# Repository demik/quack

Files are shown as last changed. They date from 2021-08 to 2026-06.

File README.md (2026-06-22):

# Quack Mouse Converter   [][License]&nbsp;[][CI]

A dongle that allows various retro systems to use the `Apple Desktop Bus` as well as `Bluetooth 2+` mice through their `quadrature` mouse ports.

<br>
<br>
<br>

<div align = center>

[][Documentation]   
[][Firmware]   
[][PCB]   
[][Changelog]

<br>
<br>

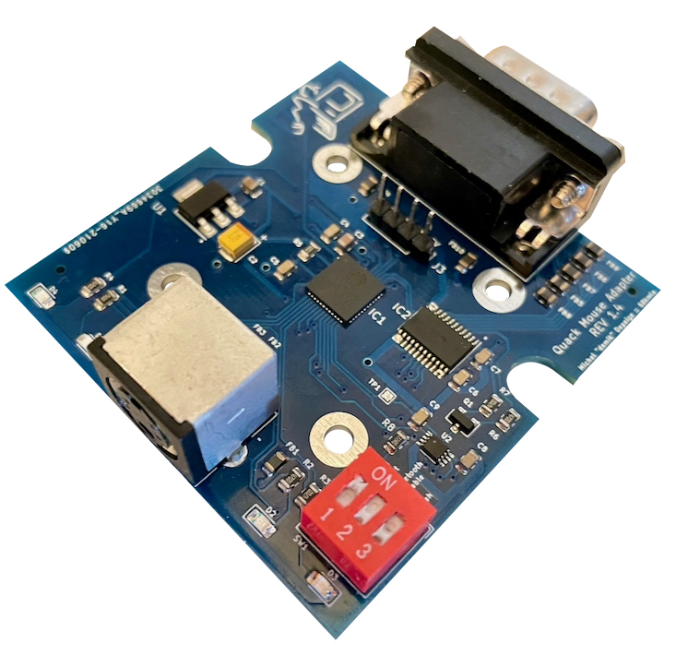
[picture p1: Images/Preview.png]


</div>

<br>
<br>

## Supported

#### Systems

<kbd>&nbsp;&nbsp;Macintosh 128 / 512 / Plus&nbsp;&nbsp;</kbd> 
<kbd>&nbsp;&nbsp;Apple Lisa&nbsp;&nbsp;</kbd> 
<kbd>&nbsp;&nbsp;Apple IIc&nbsp;&nbsp;</kbd> 
<a href="https://github.com/DosFox1/OSHintosh"><kbd>&nbsp;&nbsp;OSHintosh&nbsp;&nbsp;</kbd></a>

#### Connection Types

<kbd>  Apple Desktop Bus  </kbd> <kbd>  Bluetooth Classic 2+  </kbd>

<br>
<br>

<!----------------------------------------------------------------------------->

[Documentation]: https://github.com/demik/quack/wiki

[Changelog]: ChangeLog.md
[Firmware]: main/README.md
[License]: LICENSE
[PCB]: EDA/ChangeLog.md
[CI]: https://github.com/demik/quack/actions/workflows/idf.yml
[OSHintosh]: https://github.com/DosFox1/OSHintosh

<!-------------------------------[ Badges ]----------------------------------->

[Badge License]: https://img.shields.io/badge/License-Apache_2.0-961b1f?labelColor=D22128
[Badge CI]: https://github.com/demik/quack/actions/workflows/idf.yml/badge.svg?branch=master&event=push

<!-------------------------------[ Buttons ]----------------------------------->

[Button Documentation]: https://img.shields.io/badge/Documentation-0099E5?style=for-the-badge&logoColor=white&logo=BookStack
[Button Changelog]: https://img.shields.io/badge/Changelog-21375A?style=for-the-badge&logoColor=white&logo=AzureArtifacts
[Button Firmware]: https://img.shields.io/badge/Firmware-E5426E?style=for-the-badge&logoColor=white&logo=ROS
[Button PCB]: https://img.shields.io/badge/PCB-007c40?style=for-the-badge&logoColor=white&logo=PowerApps

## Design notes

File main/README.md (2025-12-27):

# Quack Firmware source code

### Supported SDK versions:

The code is designed to be build with ESP-IDF SDK version 5.5.2. To workaround some patchs or limitations of this specific release, you need to apply the patch located in the SDK subfolder

### Unsupported mouse conversions:

Functions are grouped into "domains" in different files. Each functions has a prefix for its own domain.
For example, adb_init() is the init function for the ADB Bus and is located in the adb.c source file.

List of relevant files:
- adb.* Apple Desktop Bus related functions
- blue.* Bluetooth related functions
- esp_hid_gap.* HID GAP library from Espressif
- gpio.* raw GPIO related functions
- led.* LED related functions
- m4848.h Header for Apple Hockey Puck mouse over Bluetooth emulation
- main.c Everything start here
- quad.c Quadrature related functions (mouse port)
- wii.* Wiimote driver

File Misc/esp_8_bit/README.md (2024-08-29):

# Quack X esp_8_bit
This is a crossover between two projects, that allow you to mod a Quack board to use with esp_8_bit firmware.
The result is a two players small box that can contains a few NES games and fit near your TV.

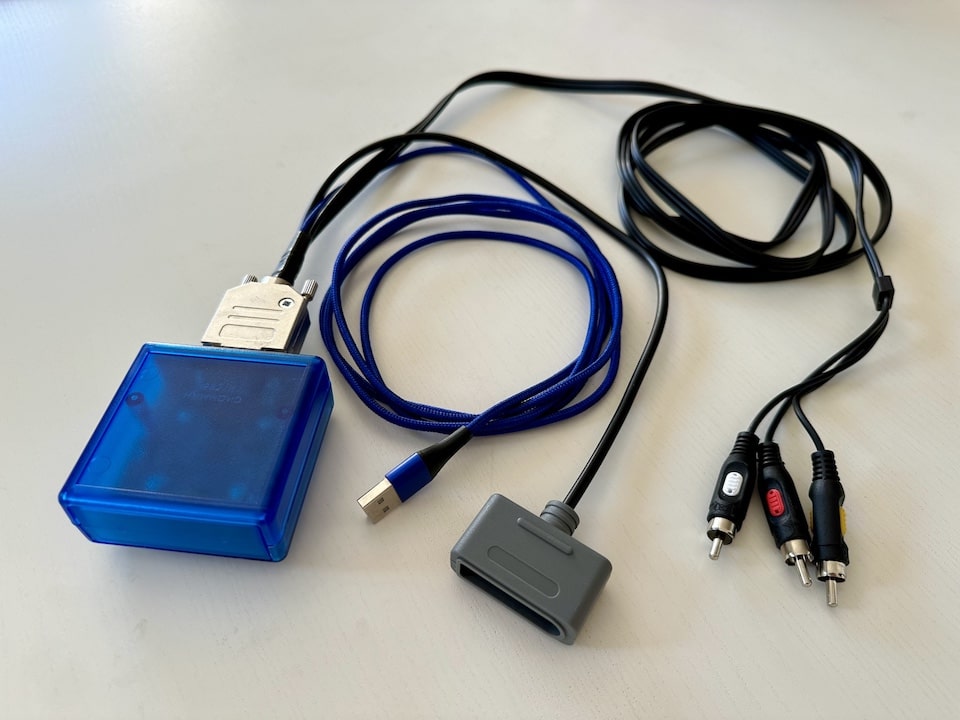
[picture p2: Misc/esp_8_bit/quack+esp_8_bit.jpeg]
quack+esp_8_bit


this is unsupported (outside of the quack project) and the parent project (esp_8_bit) is likely dead so this will likely not receive any updates or fixes

- parent project: [rossumur/esp_8_bit](https://github.com/rossumur/esp_8_bit)
- used patches from: [CornN64/esp_8_bit](https://github.com/CornN64/esp_8_bit)

it supports two players (one hardwired, either NES or SNES) and one Wiimote based. Unlike other builds, the hardwired connector runs at +5V (uses both level converters of the quack board), which allow the use of retro wireless adapters

schematic:

```
    -----------
    |         |
    |      25 |----------------------------------> video out
    |         |
    |         |   ------------
    |       2 |---| LVC 4245 |----/\/\/\/----|---> audio out
    |         |   ------------      1kΩ      |
    |         |                             ---
    |         |                             --- 10nF
    |  ESP32  |                              |
    |         |                              v gnd
    |         |
    |         |   ------------
    |       4 |---| LVC 2T45 |---< NES (or SNES) controller DATA
    |         |   ------------
    |         |   ------------
    |      12 |---| LVC 4245 |---> NES (or SNES) controller CLOCK
    |      14 |---| LVC 4245 |---> NES (or SNES) controller LATCH
    |         |   ------------
    |         |            5v <--> NES (or SNES) controller VCC
    |         |           gnd <--> NES (or SNES) controller GND
    |         |
    -----------

NES        ___
    DATA  |o o| NC
    LATCH |o o| NC
    CLOCK |o o/ 5V
    GND   |o_/

SNES       _
    5V    |o|
    CLOCK |o|
    LATCH |o|
    DATA  |o|
          |-|
    NC    |o|
    NC    |o|
    GND   |o|
           -

```

## Software

Since the esp_8_bit source code is old, you will need an old IDE (Arduino 1.8.14 with esp board 1.0.4)

there is a couple of patches in this directory that you will need to patch on top of [rossumur/esp_8_bit](https://github.com/rossumur/esp_8_bit)

- base.diff integrates patches from [CornN64/esp_8_bit](https://github.com/CornN64/esp_8_bit) and enable quack specific features (pinout, LEDs, DIP switches)
- controller.diff removes IR support, clean code and adds (S)NES controller support

```
> git clone https://github.com/rossumur/esp_8_bit.git
Cloning into 'esp_8_bit'...
remote: Enumerating objects: 345, done.
remote: Counting objects: 100% (15/15), done.
remote: Compressing objects: 100% (10/10), done.
remote: Total 345 (delta 5), reused 5 (delta 5), pack-reused 330 (from 1)
Receiving objects: 100% (345/345), 8.01 MiB | 8.04 MiB/s, done.
Resolving deltas: 100% (108/108), done.
> cd esp_8_bit
> patch -p1 < ../base.diff
patching file README.md
patching file esp_8_bit.ino
patching file 'src/emu.cpp'
patching file 'src/emu.h'
patching file 'src/emu_nofrendo.cpp'
patching file 'src/gui.cpp'
patching file 'src/hid_server/hid_server.cpp'
patching file 'src/video_out.h'
> patch -p1 < ../controller.diff
patching file 'src/ir_input.h'
patching file 'src/nintendo.h'
```

To avoid [this issue](https://github.com/rossumur/esp_8_bit/issues/19) you may want to change the partition layout as well. Check the solution into that issue, and also the boards.txt and quack_8_bit.csv files if needed

###

## Hardware

This mod is compatible with board revision 1.3 and 1.4

### PCB mods

hardware modifications needed

- remove Q1
- remove FB9
- remove D1
- bridge R1 or replace by 0Ω
- remove the Mini DIN-4 connector

Under the board:

- connect a wire from DE-9 pin 6 to D1 pin (+) on top of the board
- connect a wire from DE-9 pin 8 to Mini DIN-4 pin 1

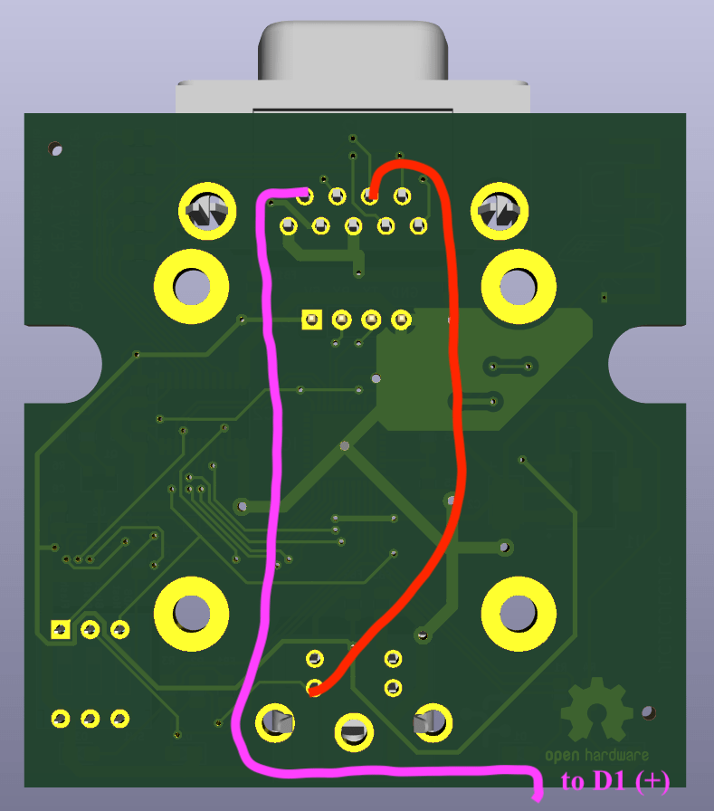
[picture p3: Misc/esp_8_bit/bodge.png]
bodge


### Adapter cable

You will need a NES or SNES extension cable, one triple RCA video cable, one USB cable (charge only is OK) and one DE-9 solderable connector
RC filtering circuit will be integrated into the connector. pinout is a follow (board side)

```
   _____________________
  /                     \
  \  1   2   3   4   5  /
   \   6   7   8   9   /
    \_________________/
```

| Pin | Connection | Notes |
|---|---|---|
| 1 | Ground | power ground & RCA shields here |
| 2 | +5V | USB +5V and (S)NES +5V connector go here |
| 3 | Ground | (S)NES ground + 10nF capacitor ground |
| 4 | NC | unused |
| 5 | Clock | (S)NES controller clock |
| 6 | Video | composite video out, yellow RCA |
| 7 | Sound | one pin of the 1kΩ resistor |
| 8 | Data | (S)NES controller data |
| 9 | Latch | (S)NES controller data |
| R | Resistor | solder capacitor on the other resistor pin & white + red RCA (+) wires |

isolate everything with hot glue or better

## Usage

Nothing different than the parent project as far as emulation goes

### Switches

Quack set of dip switches allows for the following settings

- ADB Host: (S)NES controller is player A, Wiimote player B or the other way around
- Bluetooth Disable: Kill BT Operation if not needed. More stable / less noise. Use with ADB Host to ON
- Flash: flash mode (GPIO0 to GND)

### LED

PCB LEDs are usable and do have basic functionality

- green: init done, board powered up
- yellow: valid (S)NES controller input received
- red: embedded flash operation in progress

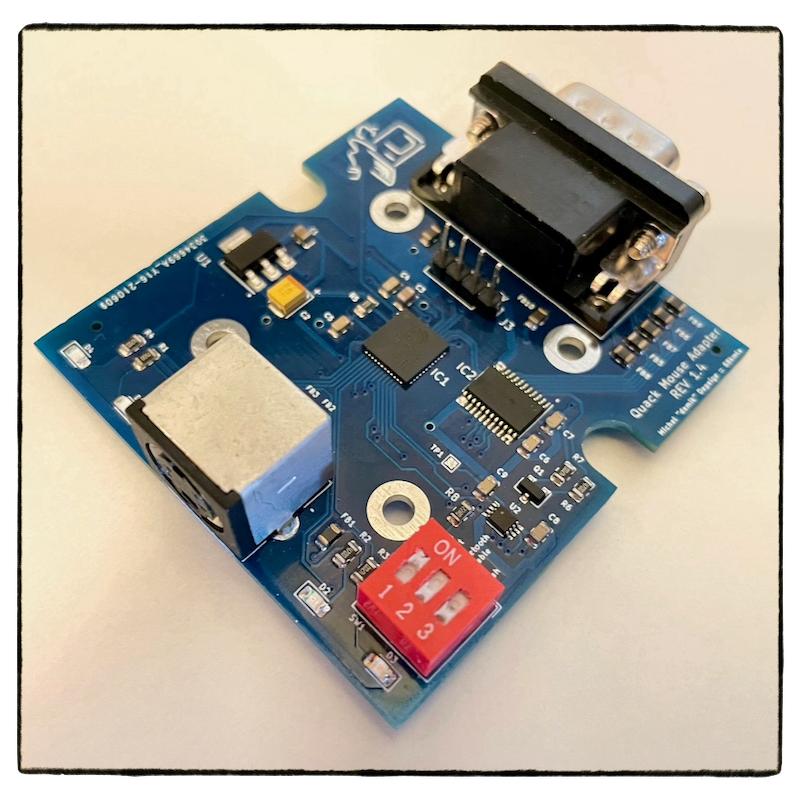
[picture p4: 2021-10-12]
Images/board.png

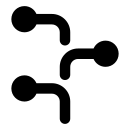
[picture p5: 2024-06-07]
EDA/Panels/Front/ADB.png

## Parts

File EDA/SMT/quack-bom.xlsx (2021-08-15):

quack-bom
Comment | Designator | Footprint | LCSC part number
ESP32-PICO-D4 | IC1 | QFN-48_EP_7.0x7.0x0.5P | C193707
74LVC4245APWR | IC2 | TSSOP-24_4.4x7.8x0.65P | C7859
10uF 25V | C1 C3 | 0805 | C15850
Tantalum 100uF 6.3V | C2 | 3528 | C16133
AMS1117-3.3 | U1 | SOT-223 | C6186
74LVC2T45DCURG4 | U2 | VSSOP-8_2.0x2.3x0.5P | C139382
Blue LED | D1 | 0805 | C2293
Yellow LED | D2 | 0805 | C2296
Red LED | D3 | 0805 | C84256
Green LED | D4 | 0805 | C2297
MOFSET P–Channel | Q1 | SOT-23-3 | C8492
22Ω ±1% 1/8W | R8 | 0805 | C17561
470Ω ±1% 1/8W | R1 R2 R3 R6 R7 | 0805 | C17710
1.2kΩ ±1% 1/8W | R4 | 0805 | C17379
100NF 50V | C4 C5 C6 C7 C8 C9 | 0805 | C49678
10KΩ ±1% 1/8W | R5 | 0805 | C17414
Bead 0805 | FB1 FB2 FB3 FB4 FB5 FB6 FB7 FB8 FB9 FB10 | 0805 | C1017

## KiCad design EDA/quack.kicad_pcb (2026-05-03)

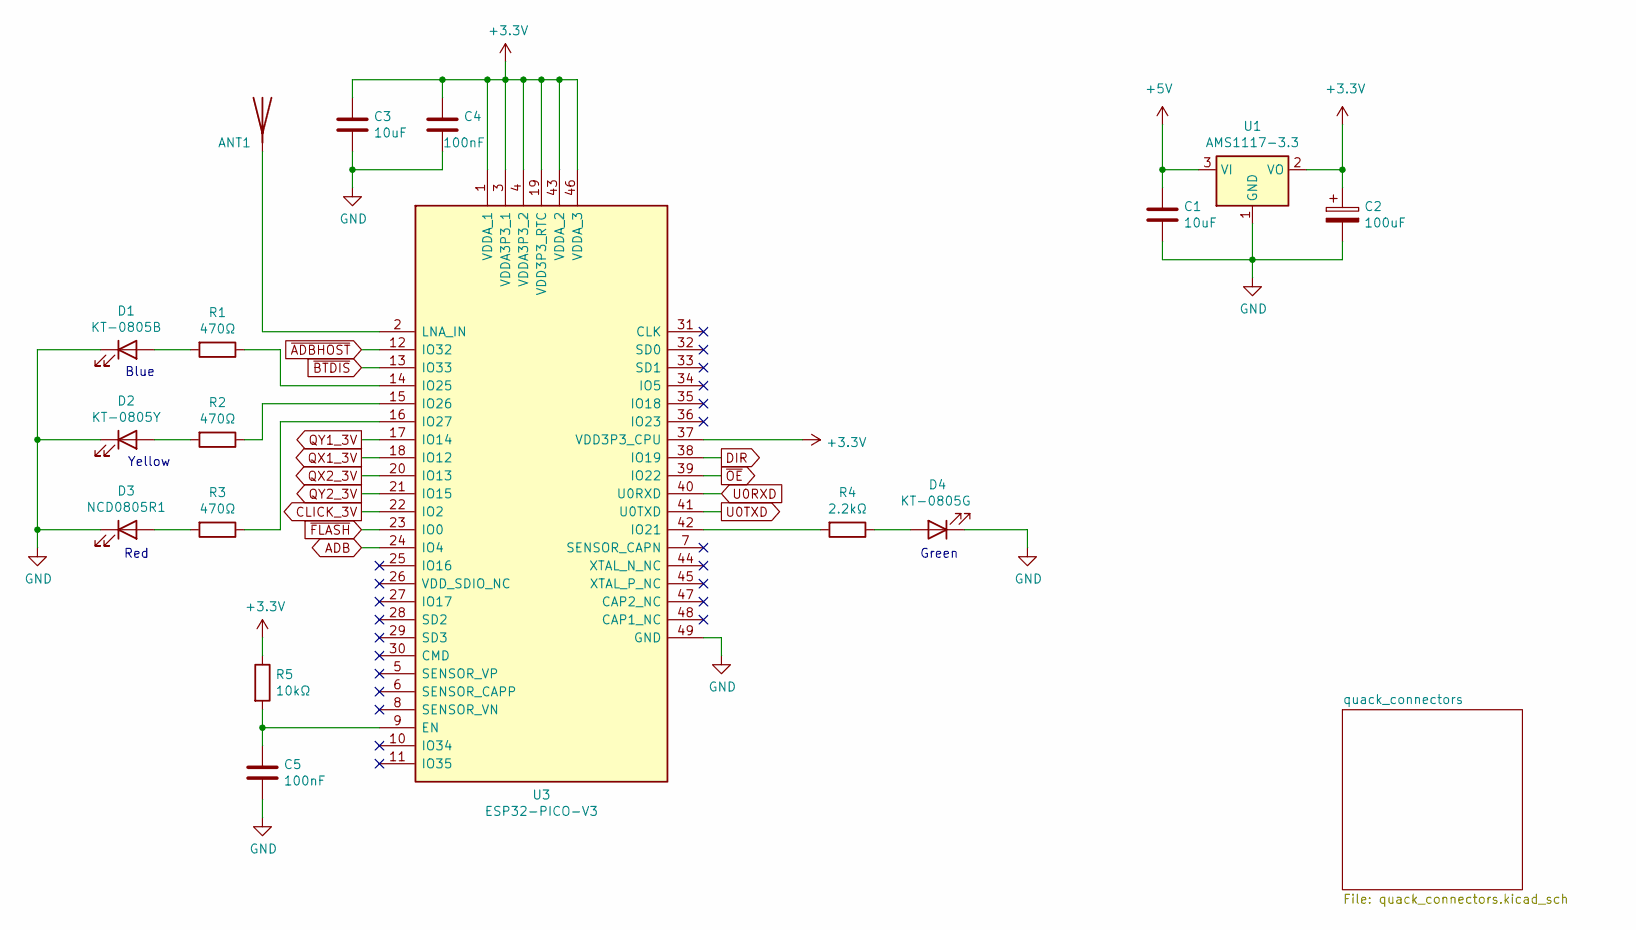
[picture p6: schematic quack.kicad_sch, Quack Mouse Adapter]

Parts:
ANT1: Antenna_Shield; Texas_SWRA117D_2.4GHz_Right
C1, C3: 10uF; C_0805_2012Metric
C2: 100uF; CP_EIA-3528-12_Kemet-T
C4, C5: 100nF; C_0805_2012Metric
D1: KT-0805B; LED_0805_2012Metric
D2: KT-0805Y; LED_0805_2012Metric
D3: NCD0805R1; LED_0805_2012Metric
D4: KT-0805G; LED_0805_2012Metric
R1, R2, R3: 470Ω; R_0805_2012Metric
R4: 2.2kΩ; R_0805_2012Metric
R5: 10kΩ; R_0805_2012Metric
U1: AMS1117-3.3; SOT-223-3_TabPin2
U3: ESP32-PICO-V3; QFN-48-1EP_7x7mm_P0.5mm_EP5.3x5.3mm; Mouser Part Number 356-ESP32-PICO-V3

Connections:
+3.3V: C2.1, C3.1, C4.1, R5.1, U1.2 (VO), U3.1 (VDDA_1), U3.3 (VDDA3P3_1), U3.4 (VDDA3P3_2), U3.19 (VDD3P3_RTC), U3.37 (VDD3P3_CPU), U3.43 (VDDA_2), U3.46 (VDDA_3); also elsewhere on the board
+5V: C1.1, U1.3 (VI); also elsewhere on the board
ADB: U3.24 (IO4); also elsewhere on the board
CLICK_3V: U3.22 (IO2); also elsewhere on the board
DIR: U3.38 (IO19); also elsewhere on the board
GND: C1.2, C2.2, C3.2, C4.2, C5.2, D1.1 (K), D2.1 (K), D3.1 (K), D4.1 (K), U1.1 (GND), U3.49 (GND); also elsewhere on the board
unnamed: ANT1.1 (A), U3.2 (LNA_IN)
unnamed: D1.2 (A), R1.2
unnamed: D2.2 (A), R2.2
unnamed: D3.2 (A), R3.2
unnamed: D4.2 (A), R4.1
unnamed: C5.1, R5.2, U3.9 (EN)
unnamed: R4.2, U3.42 (IO21)
unnamed: R1.1, U3.14 (IO25)
unnamed: R2.1, U3.15 (IO26)
unnamed: R3.1, U3.16 (IO27)
QX1_3V: U3.18 (IO12); also elsewhere on the board
QX2_3V: U3.20 (IO13); also elsewhere on the board
QY1_3V: U3.17 (IO14); also elsewhere on the board
QY2_3V: U3.21 (IO15); also elsewhere on the board
U0RXD: U3.40 (U0RXD); also elsewhere on the board
U0TXD: U3.41 (U0TXD); also elsewhere on the board
~ADBHOST: U3.12 (IO32); also elsewhere on the board
~BTDIS: U3.13 (IO33); also elsewhere on the board
~FLASH: U3.23 (IO0); also elsewhere on the board
~OE: U3.39 (IO22); also elsewhere on the board

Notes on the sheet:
Blue
Red
Green
Yellow

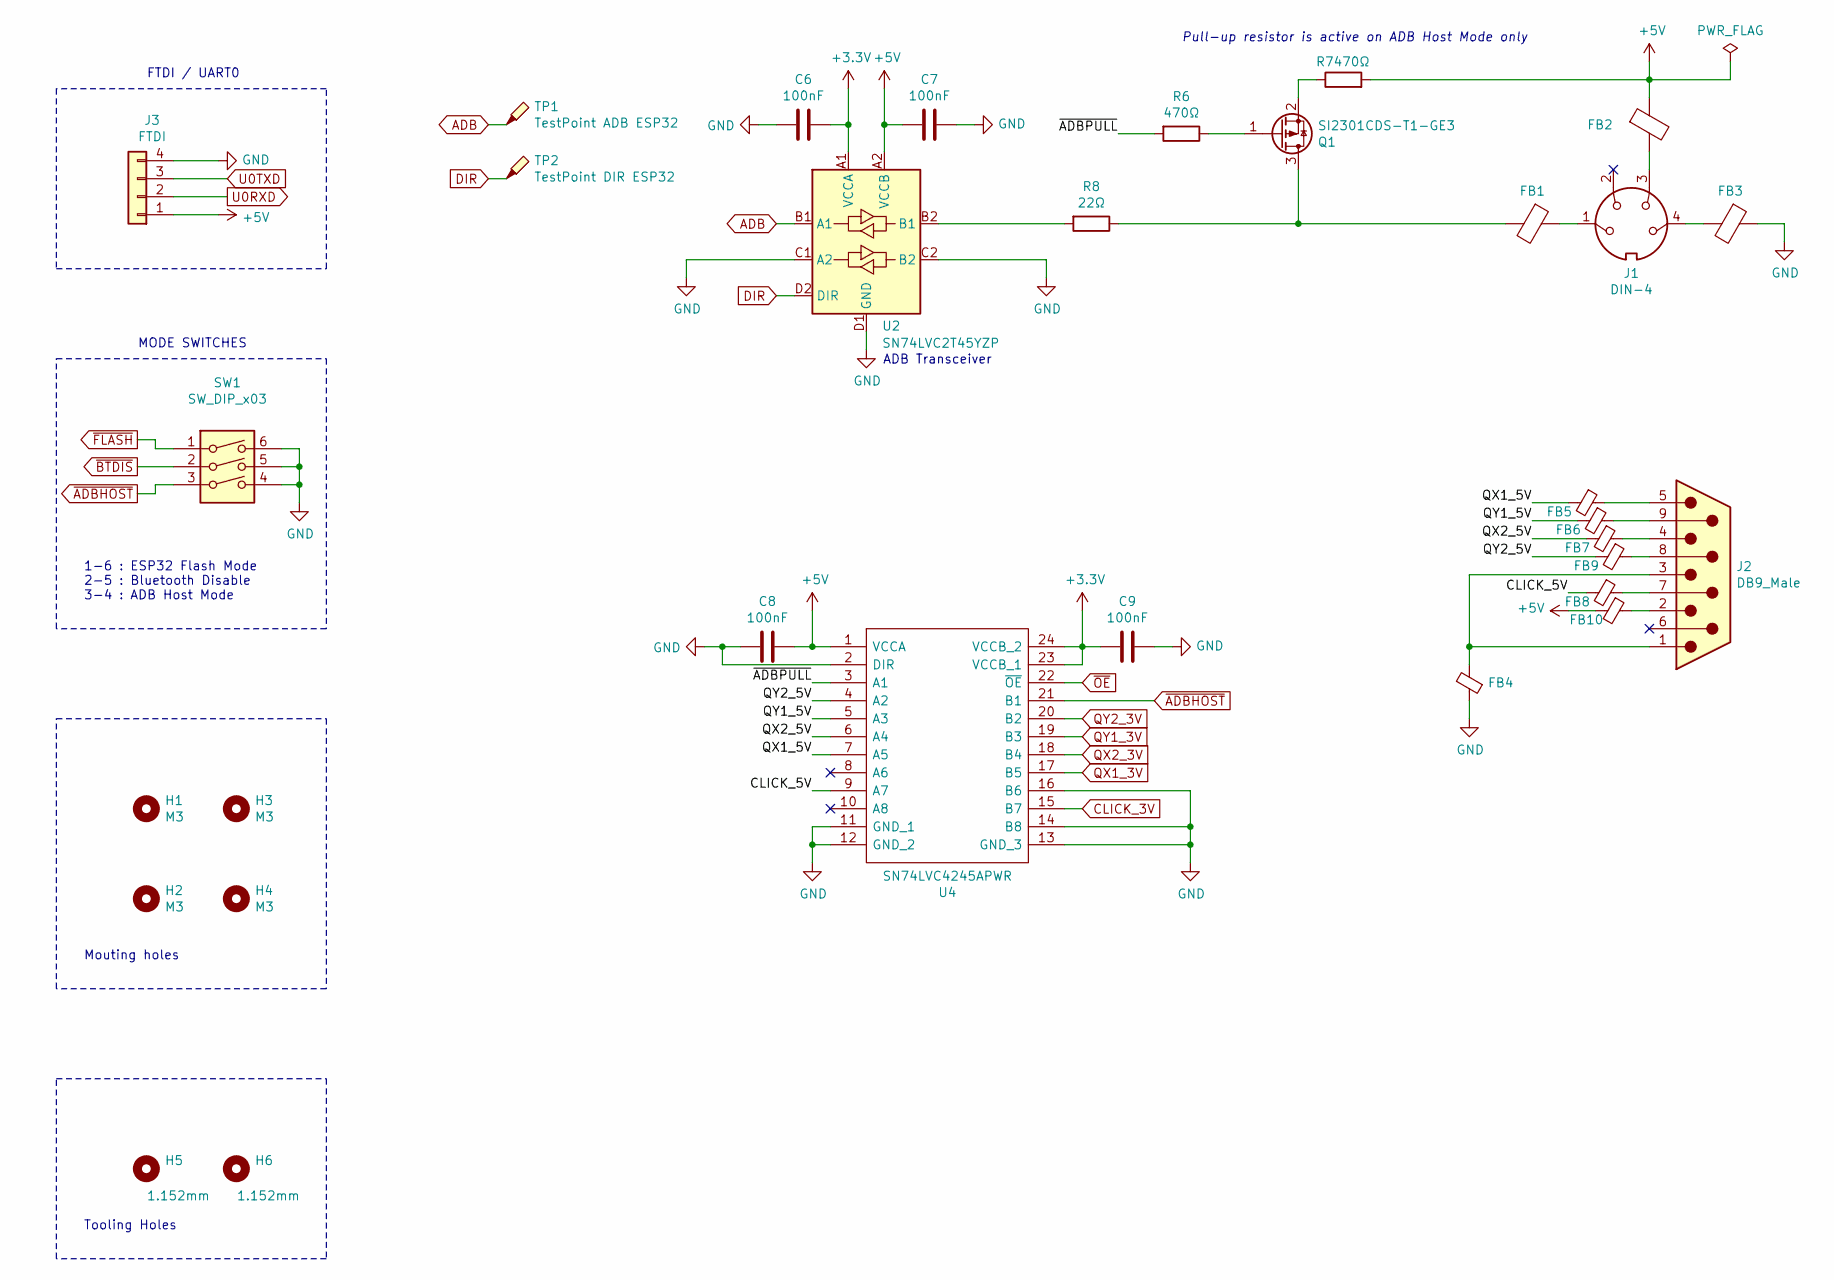
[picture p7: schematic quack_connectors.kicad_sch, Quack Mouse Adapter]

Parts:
C6, C7, C8, C9: 100nF; C_0805_2012Metric
FB1, FB2, FB3, FB4, FB5, FB6, FB7, FB8, FB9, FB10: GZ2012D601TF; L_0805_2012Metric
H1, H2, H3, H4: M3; MountingHole_3.2mm_M3_Pad
H5, H6: 1.152mm; MountingHole_1.152mm
J1: DIN-4; 5749181-1
J2: DB9_Male; 23018431
J3: FTDI; PinHeader_1x04_P2.54mm_Vertical
Q1: SI2301CDS-T1-GE3; SOT-23
R6, R7: 470Ω; R_0805_2012Metric
R8: 22Ω; R_0805_2012Metric
SW1: SW_DIP_x03; SW_DIP_SPSTx03_Slide_9.78x9.8mm_W7.62mm_P2.54mm
TP1: TestPoint ADB ESP32; TestPoint_Pad_1.0x1.0mm
TP2: TestPoint DIR ESP32; TestPoint_Pad_1.0x1.0mm
U2: SN74LVC2T45YZP; Texas_DSBGA-8_0.9x1.9mm_Layout2x4_P0.5mm
U4: SN74LVC4245APWR; TSSOP-24_4.4x7.8mm_P0.65mm; Mouser Part Number 595-SN74LVC4245APWR

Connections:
+3.3V: C6.1, C9.2, U2.A1 (VCCA), U4.23 (VCCB_1), U4.24 (VCCB_2); also elsewhere on the board
+5V: C7.2, C8.1, FB2.1, FB10.2, J3.1, R7.2, U2.A2 (VCCB), U4.1 (VCCA); also elsewhere on the board
/quack_connectors/CLICK_5V: FB8.2, U4.9 (A7)
/quack_connectors/QX1_5V: FB5.2, U4.7 (A5)
/quack_connectors/QX2_5V: FB7.2, U4.6 (A4)
/quack_connectors/QY1_5V: FB6.2, U4.5 (A3)
/quack_connectors/QY2_5V: FB9.2, U4.4 (A2)
/quack_connectors/~ADBPULL: R6.2, U4.3 (A1)
ADB: TP1.1, U2.B1 (A1); also elsewhere on the board
CLICK_3V: U4.15 (B7); also elsewhere on the board
DIR: TP2.1, U2.D2 (DIR); also elsewhere on the board
GND: C6.2, C7.1, C8.2, C9.1, FB3.1, FB4.1, J3.4, SW1.4, SW1.5, SW1.6, U2.C1 (A2), U2.C2 (B2), U2.D1 (GND), U4.2 (DIR), U4.11 (GND_1), U4.12 (GND_2), U4.13 (GND_3), U4.14 (B8), U4.16 (B6); also elsewhere on the board
unnamed: FB1.1, J1.1
unnamed: FB2.2, J1.3
unnamed: FB3.2, J1.4
unnamed: FB4.2, J2.1, J2.3
unnamed: FB5.1, J2.5
unnamed: FB6.1, J2.9
unnamed: FB7.1, J2.4
unnamed: FB8.1, J2.7
unnamed: FB9.1, J2.8
unnamed: FB10.1, J2.2
unnamed: FB1.2, Q1.3 (D), R8.1
unnamed: Q1.1 (G), R6.1
unnamed: Q1.2 (S), R7.1
unnamed: R8.2, U2.B2 (B1)
QX1_3V: U4.17 (B5); also elsewhere on the board
QX2_3V: U4.18 (B4); also elsewhere on the board
QY1_3V: U4.19 (B3); also elsewhere on the board
QY2_3V: U4.20 (B2); also elsewhere on the board
U0RXD: J3.2; also elsewhere on the board
U0TXD: J3.3; also elsewhere on the board
~ADBHOST: SW1.3, U4.21 (B1); also elsewhere on the board
~BTDIS: SW1.2; also elsewhere on the board
~FLASH: SW1.1; also elsewhere on the board
~OE: U4.22 (~OE); also elsewhere on the board

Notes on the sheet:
1-6 : ESP32 Flash Mode 2-5 : Bluetooth Disable 3-4 : ADB Host Mode
Mouting holes
MODE SWITCHES
ADB Transceiver
Pull-up resistor is active on ADB Host Mode only
Tooling Holes
FTDI / UART0

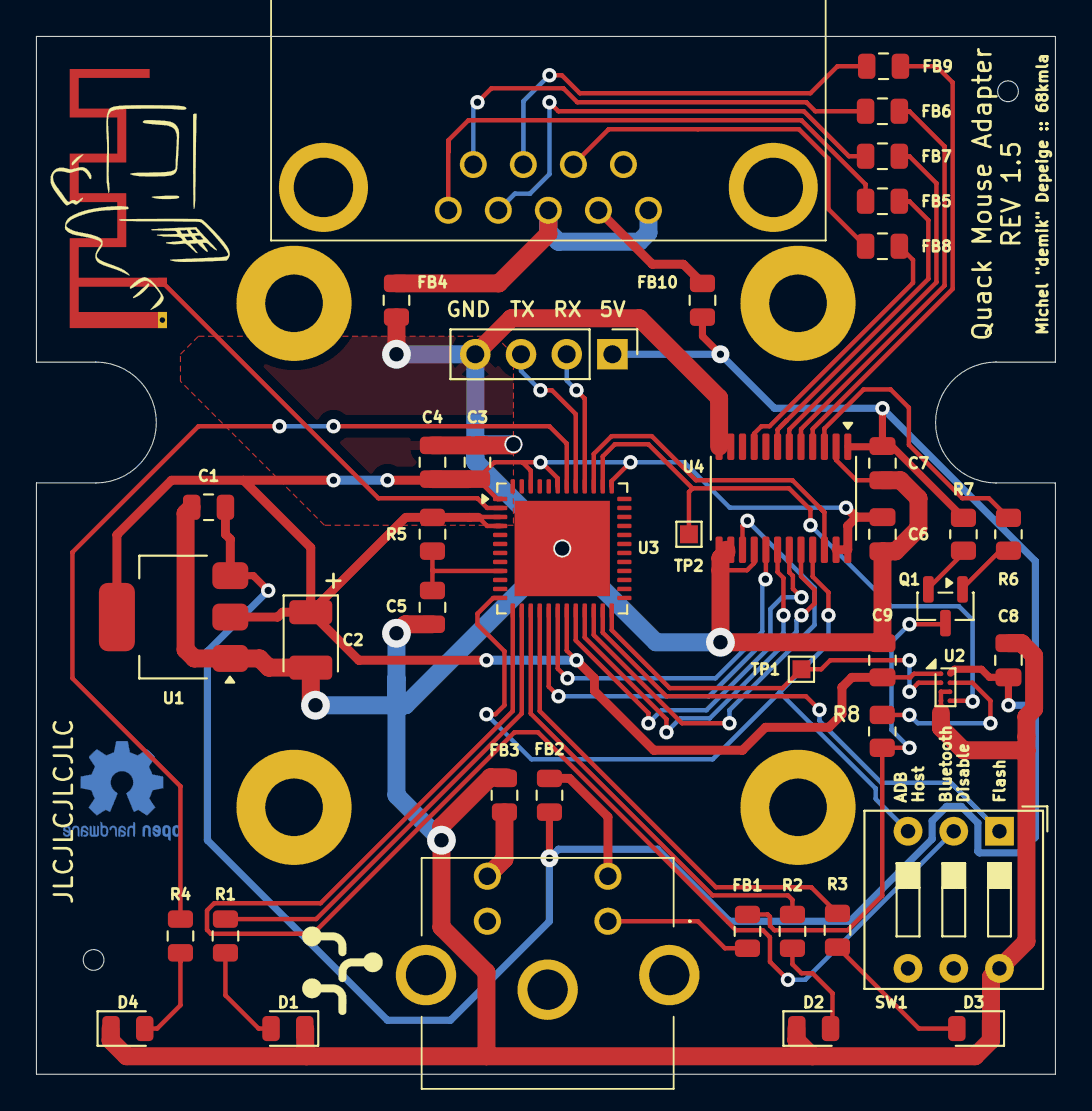
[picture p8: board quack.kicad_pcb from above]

Board: 2 copper layers, 56.6 x 57.7 mm, 49 parts (0 on the bottom side), 46 nets.

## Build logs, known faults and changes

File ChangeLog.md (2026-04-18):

## v1.5.0
- update to ESP-IDF v5.5.4
	- https://github.com/espressif/esp-idf/releases/tag/v5.5.4
	- this fixes a few buffers overflows and other rare stuff in Bluedroid
- 1.5.x series is compatible with 1.3 to 1.5 PCBs (EDA subfolder)
- new bespoke ADB RX driver has been developed based on the legacy RMT driver
	- the functionality is the same as the v1.4 one but it's more SDK future proof

## v1.4.11
- update to ESP-IDF v5.4.2
	- https://github.com/espressif/esp-idf/releases/tag/v5.4.2
	- under the hood fixes of some rare stabilities issues

## v1.4.10
- update to ESP-IDF v5.4.0
	- https://github.com/espressif/esp-idf/releases/tag/v5.4
	- fixed stabilities where Quack would reboot on BT disconnect
- added support for Apple Mighty Mouse (Bluetooth)

## v1.4.9
- added basic support for some PDP Rock Candy Wiimotes
	- BDAs starting from the range 08:03:64
	- remote doesn't reconnect correctly, have to repair each time

## v1.4.8
- added support for MacAlly Joystick
- added support for Nintendo Wiimotes
	- D-pad movement working, click on B, half-click on A
	- selectable movement speed on the Weemote + LED feedback
	- this lay the framework to add drivers for some unsupported devices

## v1.4.7
- new feature: half click on right BT click (similar to some ADB devices)
- workarounds for v1.4.6 green led regression

## v1.4.6
- added support for ADB composite devices (Kensignton and some Joysticks)
- fixed ADB start and stop bit times (65 µs vs 70 µs, error in AN591)
- update to ESP-IDF v5.2.2
	- https://github.com/espressif/esp-idf/releases/tag/v5.2.2
	- fixed flash corruption after pairing too much devices (20+)
	- fixed ADB host mode where the ESP boot was too fast (v5.2 regression)

## v1.4.5
- update to ESP-IDF v5.1.2
	- https://github.com/espressif/esp-idf/releases/tag/v5.1.2
	- big background update, lot of cleaning and rewrites
	- as most patches are now mainstream, sdk patching is now minimal
	- removed direct ABI bluedroid call

## v1.4.4
- update to ESP-IDF v4.2.3:
	- https://github.com/espressif/esp-idf/releases/tag/v4.2.3
	- mostly bluetooth related security and bug fixes

## v1.4.3
- provides some slight acceleration and desceleration on bluetooth mouses

## v1.4.2
- added support for MicroSpeed MacTRAC 2.0
- fixed a BT led state when a device reconnect while scanning

## v1.4.1
- update to ESP-IDF v4.2.2:
	- https://github.com/espressif/esp-idf/releases/tag/v4.2.2
	- fixed controller not reporting disconnect event
- fixed BT LED state when using multiple mouses

## v1.4.0
- Initial firmare release
- 1.4.x series is compatible with 1.3 and 1.4 PCBs (EDA subfolder)

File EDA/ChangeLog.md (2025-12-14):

## PCB 1.5
- increased R4 from 1.2kΩ to 1.5kΩ
- replaced ESP32-PICO-D4 by ESP32-PICO-V3
- replaced 74LVC2T45DCURG4 by 74LVC2T45YZP
- replaced LBSS84LT1G by SI2301CDS-T1-GE3
- Silkscreen improvements
- Routing improvements
- Upgraded Project for KiCad 9.0 with glue libraries

## PCB 1.4
- added resistor on pulldown to match 68040 Macs.
- tone down LEDs again again again.
- Silkscreen corrections
- added Open Hardware logo
- added tooling holes

## PCB 1.3
- testing blue PCB
- replaced RXS0108EPWR by 74LVC2T45 + 74LVC4245
- tone down LEDs by about 30%
- added automatic ADB pullup resistor
- added decoupling capacitors to level converters

## PCB 1.2
- moved a few labels around the silk layer
- moved the ADB socket out by 2mm
- tone down LEDs by about 50% (christmas is over)
- replaced TXB0108PWR by TXS0108EPWR

## PCB 1.1
- added beads to reduce EMI
- fixed missong OE on TXB0108
- tone down LEDs by about 20%
- fixed Pick&Place rotations
- added PCB Antenna

## PCB 1.0
- Initial board release

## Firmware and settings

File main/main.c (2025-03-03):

/*
 *  main.c
 *  quack
 *
 *  Created by Michel DEPEIGE on 14/12/2020.
 *  Copyright (c) 2020 Michel DEPEIGE.
 *
 * This program is free software; you can redistribute it and/or modify
 * it under the terms of the Apache License, Version 2.0 (the "License");
 * You may obtain a copy of the License at:
 *
 *      http://www.apache.org/licenses/LICENSE-2.0
 *
 * Unless required by applicable law or agreed to in writing, software
 * distributed under the License is distributed on an "AS IS" BASIS,
 * WITHOUT WARRANTIES OR CONDITIONS OF ANY KIND, either express or implied.
 * See the License for the specific language governing permissions and
 * limitations under the License.
 *
 */

#include <stdio.h>
#include "driver/gpio.h"
#include "sdkconfig.h"
#include "freertos/FreeRTOS.h"
#include "freertos/task.h"
#include "esp_flash.h"
#include "esp_hidh.h"
#include "esp_log.h"
#include "esp_system.h"
#include "esp_chip_info.h"
#include "esp_gap_bt_api.h"

#include "adb.h"
#include "blue.h"
#include "led.h"
#include "gpio.h"
#include "quad.h"

/* global TAG for ESP_LOG */
static const char* TAG = "quack";

void app_main(void)
{
	uint32_t flash_size;
	esp_flash_get_size(NULL, &flash_size);

	/* Print chip information */
	esp_chip_info_t chip_info;
	esp_chip_info(&chip_info);
	ESP_LOGI(TAG, "This is %s chip with %d CPU cores, WiFi%s%s, "
			"revision %d, %" PRIu32 "MB %s flash",
			CONFIG_IDF_TARGET,
			chip_info.cores,
			(chip_info.features & CHIP_FEATURE_BT) ? "/BT" : "",
			(chip_info.features & CHIP_FEATURE_BLE) ? "/BLE" : "",
			chip_info.revision, flash_size / (1024 * 1024),
			(chip_info.features & CHIP_FEATURE_EMB_FLASH) ? "embedded" : "external");

	ESP_LOGI(TAG, "Minimum free heap size: %" PRIu32 " bytes", esp_get_minimum_free_heap_size());
	ESP_LOGI(TAG, "");
	ESP_LOGI(TAG, "\\_o< \\_o< \\_o< \\_O<");
	ESP_LOGI(TAG, "");

	gpio_init();
	led_init();
	quad_init();
	adb_init();

	/*
	 * Check /BTOFF and enable bluetooth if needed
	 * of bluetooth is disabled, enable quadrature outputs
	 */
	if (gpio_get_level(GPIO_BTOFF) == 1)
		blue_init();
	else
		gpio_transceiver_enable();

	/* put LED error ON if no inputs (/BTOFF and no /ADBSRC) */
	if (gpio_get_level(GPIO_BTOFF) == 0 && gpio_get_level(GPIO_ADBSRC) == 1) {
		ESP_LOGE(TAG, "Bluetooth is off and ADB is NOT in host mode!");
		xTaskNotify(t_red, LED_ON, eSetValueWithOverwrite);
	}
}

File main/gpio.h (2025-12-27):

/*
 *  gpio.h
 *  quack
 *
 *  Created by Michel DEPEIGE on 13/09/2020.
 *  Copyright (c) 2020 Michel DEPEIGE.
 *
 * This program is free software; you can redistribute it and/or modify
 * it under the terms of the Apache License, Version 2.0 (the "License");
 * You may obtain a copy of the License at:
 *
 *      http://www.apache.org/licenses/LICENSE-2.0
 *
 * Unless required by applicable law or agreed to in writing, software
 * distributed under the License is distributed on an "AS IS" BASIS,
 * WITHOUT WARRANTIES OR CONDITIONS OF ANY KIND, either express or implied.
 * See the License for the specific language governing permissions and
 * limitations under the License.
 *
 */

#ifndef GPIO_H
#define GPIO_H

/* prototypes */
void	gpio_init(void);
void    gpio_transceiver_disable(void);
void    gpio_transceiver_enable(void);

/* GPIO pins definitions
 *
 * pin layout is compatible with ESP32-CAM module for prototyping
 * LEDs aren't avaible on ESP32-CAM but DEBUG LED (Camera connector)
 *
 * on ESP32-CAM the following pins are already used:
 * - CSI_MCLK (GPIO0)
 * - U0TXD (GPIO1)
 * - U0TXD (GPIO3)
 * - FLASH (GPIO4)
 *
 * on ESP32-PICO-D4, the following pins are used for connecting the
 * embedded flash:
 * - CLK (GPIO6)
 * - SD0 (GPIO7)
 * - SD1 (GPIO8)
 * - CMD (GPIO11)
 * - GPIO16
 * - GPIO17
 */

#define GPIO_ADB		4
#define GPIO_CLICK		2
#define GPIO_QX1		12
#define GPIO_QX2		13
#define GPIO_QY1		14
#define GPIO_QY2		15

#define GPIO_DIR		19
#define GPIO_OE		22
#define GPIO_ADBSRC		32
#define GPIO_BTOFF		33

#define GPIO_GREENLED	21
#define GPIO_BLUELED	25
#define GPIO_YELLOWLED	26
#define GPIO_REDLED		27

#define GPIO_NULL		5

#endif

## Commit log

2020-09-15 added pin usage text + logos
    [quack.kicad_pcb]
2020-09-25 added beads to reduce EMI
    [quack.kicad_pcb, quack_connectors.sch]
2020-12-14 starting to work with LEDs
2020-12-16 added led management tasks
2020-12-18 board revision 1.1
    [quack-bom.xlsx, quack.kicad_pcb, quack.sch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]
2020-12-21 added missing GPIO + disable Bluetooth if /BTOFF
    [gpio.c, gpio.h, main.c]
2020-12-30 revision 1.2: move ADB socket 2mm out
    [quack.kicad_pcb, quack.sch, quack_connectors.sch]
2021-01-08 Board revision 1.2
    [quack-bom.xlsx, quack.kicad_pcb, quack.sch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]
2021-01-11 init ADB devices correctly
    [adb.c]
2021-03-21 start of ADB stack: send reset command on startup
    [adb.c, gpio.c]
2021-04-03 replaced RXS0108EPWR by 74LVC2T45 + 74LVC4245
    [quack.kicad_pcb, quack.sch, quack_connectors.sch]
2021-04-03 mix fixes: silk, routing, 3D shapes
    [quack.kicad_pcb, quack.sch, quack_connectors.sch]
2021-04-04 fixed quad transceiver footprint + reduce led brightness
    [quack-bom.xlsx, quack.kicad_pcb, quack.sch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]
2021-04-05 PCB version 1.3
    [quack-bom.xlsx, quack.kicad_pcb, quack.sch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]
2021-04-05 fixed some SMT positions for pick and place
    [quack-all-pos.xlsx]
2021-04-17 added mounting holes to schematic
    [quack.kicad_pcb, quack.sch, quack_connectors.sch]
2021-05-03 ADB Parsing 90% done, quadrature output issues
    [adb.c, gpio.c, gpio.h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]
2021-05-07 Changed pin code to 0000
2021-05-08 increase tick rate to 250Hz
2021-05-08 fixed timings and code cleaning
    [adb.c]
2021-05-08 Quadratures fixes: x movement, pullups, timings
    [gpio.c, quad.c]
2021-05-31 fixed ADB Sync timing
    [adb.c]
2021-06-08 PCB v1.4
    [quack-bom.xlsx, quack.kicad_pcb, quack.sch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]
2021-08-05 increase RMT buffer and stability on data rx errors
    [adb.c]
2021-08-15 fixed R1 and R4 values
    [quack-bom.xlsx, quack.kicad_pcb, quack.sch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]
2021-08-16 rotated U2 by 90°
    [quack-all-pos.xlsx]
2021-08-16 moved LEDs to LEDC module, fade slow blink, and move LEDs to CPU 1
2021-08-20 switched auth to ESP_IO_CAP_OUT
2021-08-22 pin LED and ADB to core 1 again
2021-09-08 Datasheet for ADB Socket
2021-09-20 fixed BT LED state when using multiple mouses
2021-10-12 added PCB image
2021-10-30 fixed BT LED state in case some mouse is reconnecting while the quack is scanning
2022-01-04 added back panel using a PCB
    [quack_BP.kicad_pcb, quack_BP.sch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]
2022-07-05 Cut Out Preview
2024-06-04 added support for Kensington ADB Devices
2024-06-05 fix ADB start and stop bit timings
    [adb.c]
2024-06-07 added complex PCB front panel
    [quack_FP.kicad_pcb]
2024-06-08 New FR-4 based front panel with shine-through LEDs
    [quack_FP.kicad_pcb]
2024-06-17 added new FR-4 front panel
    [quack_FP.kicad_sch]
2024-08-10 esp_hidh_dev_open() doesn't give a toss about BLE address types in our case
2024-08-14 added wii remote support (buttons)
2024-08-29 added resources for esp_8_bit build
    [quack_8_bit.csv]
2024-09-25 Back panel update: Apple IIc
    [quack_BP.kicad_pcb, quack_BP.kicad_sch, quack_BP.sch]
2025-03-03 added Mighty Mouse driver
2025-03-18 added flash switch watchdog
2025-03-20 Revert "added flash switch watchdog"
    This reverts commit 9152b953aa4b516238fd8f009775ccb52d42a4be because you can't enter bootloader from esp_restart() on ESP32
    [gpio.c, gpio.h]
2025-12-14 PCB v1.5
    [quack.kicad_pcb, quack.kicad_sch, quack.sch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]
2025-12-27 upgraded SDK to v5.5.2 + new low level ADB receiver driver
2026-02-25 misc Bluetooth stability improvements with ESP-IDF v5.5
    [adb.c, led.c]
2026-04-18 reverted PCB revision to 1.5
    [quack.kicad_pcb]
2026-05-01 EDA lib: updated Mini DIN 4 connector
    [quack.kicad_pcb, quack_connectors.kicad_sch]
2026-05-01 bump emerald LED from 1.5kΩ to 2.2kΩ
    [quack.kicad_sch]
2026-05-03 moved all logos footprints to Quack_logo.pretty
2026-05-03 update PCB to use Quack_logo.pretty
    [quack.kicad_pcb]
